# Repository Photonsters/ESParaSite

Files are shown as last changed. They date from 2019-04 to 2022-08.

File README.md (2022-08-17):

# ESParaSite temperature logger (ESP Chip-based Parameter logger with integrated website)

### Compatible with ESP8266 and ESP32

The idea for this project is to make use of the empty ESP01 slot available on the photon to make a logger to keep track of various temperatures and other data on a MSLA printer by acessing the ESP with a regular browser

Here is an example of the dashboard

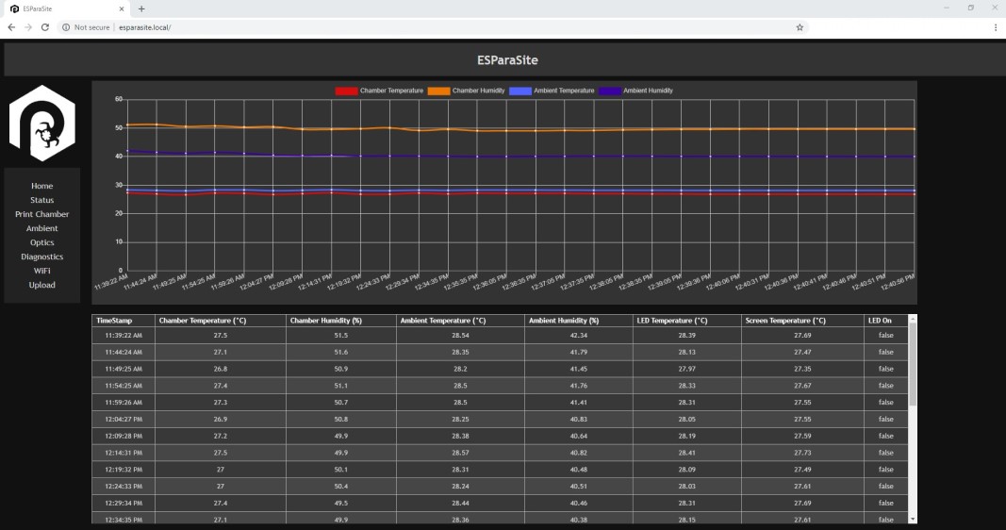
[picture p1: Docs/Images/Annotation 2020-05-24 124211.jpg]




**Check More on the [WIKI](https://github.com/Photonsters/ESParaSite_TemperatureLogger/wiki)**

Reference projects
- https://homecircuits.eu/blog/battery-powered-esp8266-iot-logger/
- http://baddotrobot.com/blog/2016/03/23/homebrew-temperature-logger/
- https://github.com/luc-github/ESP3D-WEBUI

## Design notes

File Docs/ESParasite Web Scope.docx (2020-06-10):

We are creating a data logger for 3d printers based on the ESP8266 Single board computer (type of Arduino)

The software running on the ESP8266 includes the data logger, mDNS, and a very basic webserver.

The limitations of the webserver are that it can only server files and http responses (basic web pages) so no PHP, perl or any server-side magic.

It can serve .html and .js and .css so those need to be our key tools

Not being a web guy (since the days of FrontPage, lol) I have cobbled together a website UI using

Html, css and a little javascript. Here is the “home” page.

I have run into a bunch of issues trying to do what I think is the right way to make this work.

First issue, I am loading content (home.html) into a div using jquery .load() but when I try to load other content into the div, the javascript from home.html continues to run until I call window.location.reload();

Second issue, I need to have the page refresh every 5 seconds, but after an hour or so it crashes

Third issue, I can’t get other pages to load properly no matter what I do for example (status.html) the table doesn’t execute.

The code is up on github for you to take a look.

Any help is appreciated, but mainly if you can get me going in the right direction, I am sure I can probably learn enough to make the rest work, my main struggle is just how javascript flows and interacts with the page itself.

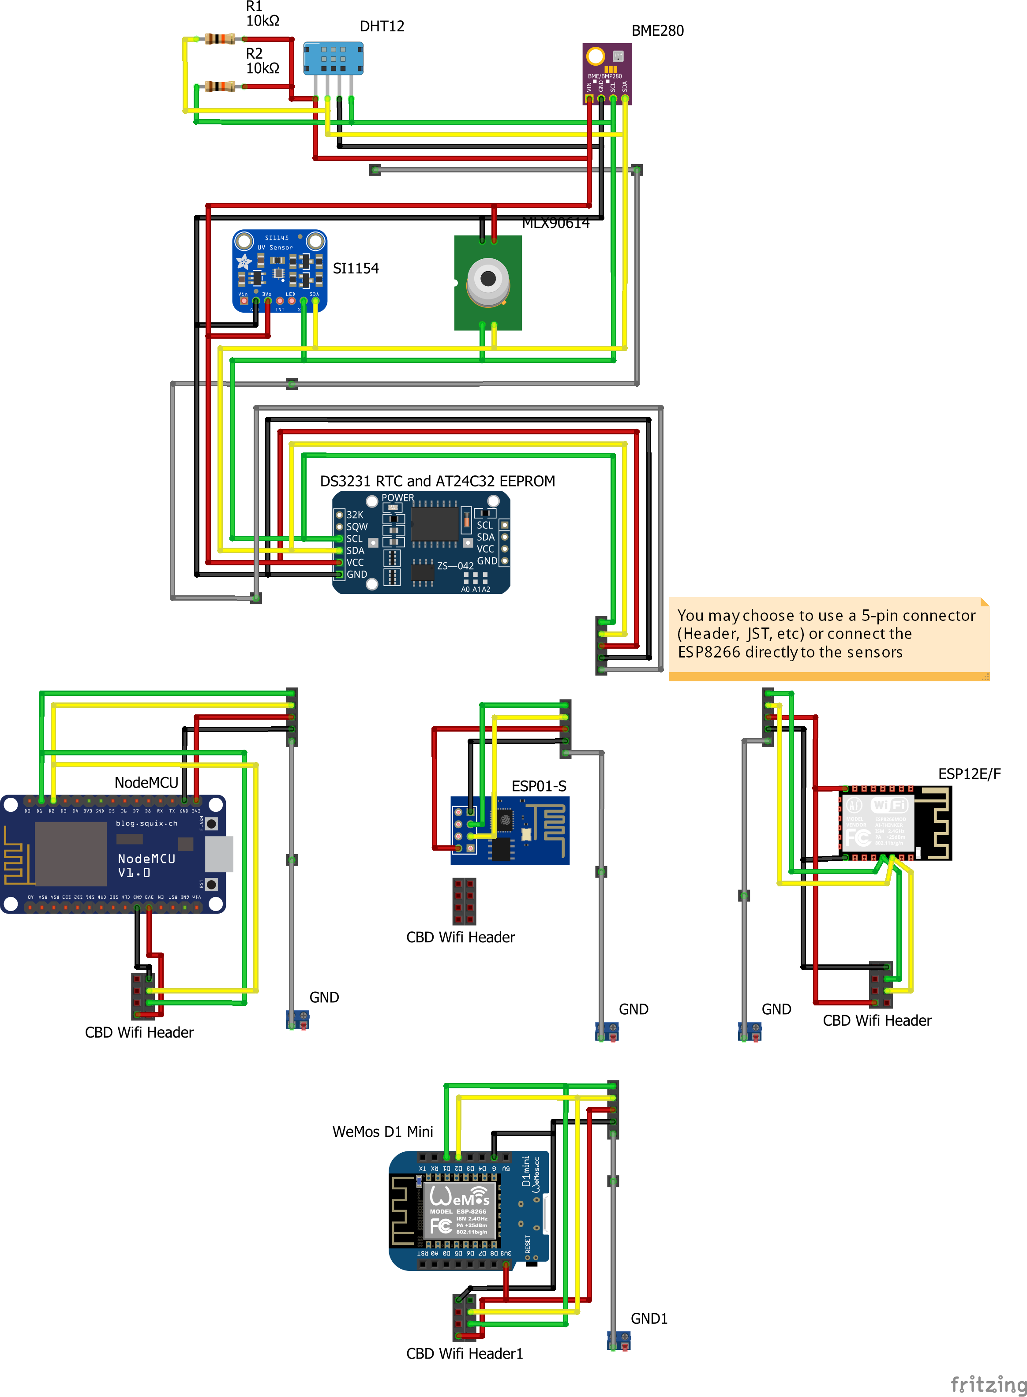
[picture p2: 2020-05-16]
Docs/Images/ESP para-site_bb.png

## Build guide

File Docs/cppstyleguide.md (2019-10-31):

ESParaSite Variable and Function naming conventions.

- NO MAGIC NUMBERS!
	- If there is a

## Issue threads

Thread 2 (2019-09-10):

Initial Config By AP Mode

CthulhuLabs, 2019-09-10:
To make it so you do not have to hard code the WiFi settings have the device initially boot up as an Access Point with a semi random SSID like "ESParaSite-1273" and no password. Use the sign in requirement of the AP force you to the config page. There have it ask for the proper SSID and Password. Once set the device resets and attempts to log into that AP. If it fails it goes back to the initial config state. If it succeeds it goes into standard operation mode.

aeakin1, 2019-09-10:
I believe this should be straightforward.  We will keep wifi config in the SPIFFS on the ESP itself.

Basic logic:
If not exists wifi config info or if wifi STA mode fails X number of times, it will boot up in AP mode and serve up a page allowing setting of SSID, Wireless PW and DHCP/Static IP.

if Wifi config is existing and connects, boot straight to STA mode.

Refer to
http://onlineshouter.com/use-esp8266-wifi-modes-station-access-point/

https://www.digikey.com/en/maker/blogs/2017/configure-your-esp8266-wifi-module-with-new-wifi-manager

aeakin1, 2019-09-16:
WiFi Manager has been successfully implemented.
If an ESParaSite boots and finds no config.json file or autoconnect credentials, It will execute the Config Portal. wifi network, password, SDA and SCL pins can be set in the portal as well as a few other handy bits of information (IP, MAC address, Board info). Once set, the portal is closed and the ESParaSite reboots, using the credentials for autoconfig.

If autoconnect fails, the unit falls back to config.json. If that fails, the Config Portal is launched.
At a later date, we will add the ability to set the fallback credentials set in the config.json file, for now they are not populated.

Closed 2019-09-16.

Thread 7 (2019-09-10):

Add (POST) RESTful capabilities for, Screen FEP and LED Counter Reset

aeakin1, 2019-09-10:

Closed 2020-05-16.

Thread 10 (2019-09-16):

Add control for Print Chamber Heater

aeakin1, 2019-09-16:
Controlling a relay via I2C seems to be difficult so this would only be available for "Advanced" boards (NodeMCU/ MiniNodeMCU/ ESP32) or potentially with a mod to an ESP-01s style board

We would use the Chamber temperature sensor and a relay to control the Heater, rather than the heater having its own controls.

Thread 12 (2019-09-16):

Lithium battery or super cap to prevent EEPROM corruption due to power off during write

aeakin1, 2019-09-16:
(High cost, High Effort, Low yield)

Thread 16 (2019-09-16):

Implement ability to set config.json fallback wifi credentials

aeakin1, 2019-09-16:
Current implementation leverages autoconnect, which uses a cached credential set during the WifiManager setup process.

Either copy autoconnect credentials or allow manual entry of the values stored in config.json for fallback.

aeakin1, 2020-06-05:
After witnessing the stability of the autoconnect routine, we are abandoning this feature.

Closed 2020-06-05.

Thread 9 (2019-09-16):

RTC EEPROM Fallback in case of corruption

aeakin1, 2019-09-16:
There is a slight chance that the Printer in which an ESParaSite is installed may be powered off while a EEPROM Write is in progress (there are 2x 50ms periods per minute in which an EEPROM update is occurring giving us a maximum risk of 100ms/60000ms. (1/100)  While this value accounts for the maximum write latency of the AT24Cxx EEPROM chip, it is likely that we would have incorrect or corrupt values.

In order to avoid this, we would need to calculate and store a checksum value on each write. All of the EEPROM values are read at boot and loaded into variables.  If this checksum fails during the read:
- we would then fall back to the previous segment of Flash (and continue to fall back until a good value is found)
- we would log an error message for each fallback
- If no good segment is found, we will format the lifetime logging segments of the EEPROM
- Potentially we will add a permanent flag that will be used to declare the EEPROM "bad" and cease logging lifetime counters until the RTC board is replaced.

Potential library
https://github.com/bakercp/CRC32

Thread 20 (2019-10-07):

Add relay control for softpower or failsafe mode

aeakin1, 2019-10-07:
The request came in as a result of a Photonster hitting a bug in the board firmware. Due to this bug, the printer was rendered powered on and somewhat operational for an extended window, while the cooling fan(s) had been shut off due to said bug. This resulted in potential damage to the LCD, LED and Mainboard components due to potential overheating.

This feature can be built to operate in two mode, selectable by the user via a config checkbox and trivial wiring change (move 1 wire from the N.O. to the N.C. screw terminal ( or visa-versa on the relay board)

# Safety shutdown mode
Safety Shutdown Mode puts a Normally Closed relay in line with the 12V power leads as they enter the chassis.

The ESParaSite can then open the relay (shutting down power to the Printer Mainboard).

## Advantages
* The ESParaSite is only responsible for opening the relay (cutting the power).
* Printing can be aborted in case of over temperature conditions being reached.
* allows us to control the printer power remotely

## Disadvantages
* less features
* If used for remote power on/off, the "off state" becomes dependent on the ESParaSite.

# Soft Power Mode
Soft Power mode puts a Normally Open relay in line with the 12V power leads as they enter the chassis.

## Advantages
* allows us to control the printer power remotely
* reduces eeprom corruption risk by allowing us to make clean writes and enter sleep mode rather than being at the mercy of when the user turns off the switch.
* allows us to cut power to the unit in case of over temperature conditions being reached.
* Could implement wake on LAN/Wifi and other handy features

## Disadvantages
* Relying on ESParaSite adds additional points of failure and complexity
* Successful prints completely depend on ESParaSite stability

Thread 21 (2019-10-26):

Add support for MS1100 VoC Sensor

aeakin1, 2019-10-26:
the MS1100 is an analog sensor for sensing VoCs.
[MS1100-ETC.pdf](https://github.com/Photonsters/ESParaSite_TemperatureLogger/files/3774395/MS1100-ETC.pdf)

X3msnake, 2019-11-26:
http://henrysbench.capnfatz.com/henrys-bench/arduino-voltage-measurements/arduino-ads1115-module-getting-started-tutorial/

X3msnake, 2019-11-27:
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

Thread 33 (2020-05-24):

GUI - Status Page

aeakin1, 2020-05-24:
Status page should show

Network Box:
Wifi status and signal strength
IP config
mDNS status

Other Status:
Eeprom last write timestamp
Printer life seconds
FEP life seconds
LCD life seconds
LED Life Seconds
Case Temperature

aeakin1, 2020-06-05:
Complete

Closed 2020-06-05.

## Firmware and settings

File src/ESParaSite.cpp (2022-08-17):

// ESParaSite.cpp

/* ESParaSite-ESP32 Data Logger
        Authors: Andy (SolidSt8Dad) Eakin

        Please see /ATTRIB for full credits and OSS License Info
        Please see /LIBRARIES for necessary libraries
        Please see /VERSION for Hstory

        All Derived Content is subject to the most restrictive licence of it's
        source.

        All Original content is free and unencumbered software released into the
        public domain.

        The Author(s) are extremely grateful for the amazing open source
        communities that work to support all of the sensors, microcontrollers,
        web standards, etc.
*/

#include <Arduino.h>
#include <FS.h>
#include <I2C_eeprom.h>

#include "API.h"
#include "ConfigPortal.h"
#include "Core.h"
#include "DebugUtils.h"
#include "ESParaSite.h"
#include "Eeprom.h"
#include "FileCore.h"
#include "Http.h"
#include "Sensors.h"
#include "Util.h"


#ifdef ESP32

#include <ESPmDNS.h>
#include <WiFi.h>

#include "ESP32.h"

#else

#include <ESP8266WiFi.h>
#include <ESP8266mDNS.h>

#include "ESP8266.h"

#endif

#ifdef ESP32

#include <SPIFFS.h>
FS *filesystem = &SPIFFS;
#define FileFS SPIFFS

#else

#include <LittleFS.h>
FS *filesystem = &LittleFS;
#define FileFS LittleFS

#endif

// The structs used to carry data globally
ESParaSite::ambientData ambient;
ESParaSite::configData config;
ESParaSite::enclosureData enclosure;
ESParaSite::opticsData optics;
ESParaSite::chamberData chamber;
ESParaSite::eepromData eeprom;
ESParaSite::statusData status;
ESParaSite::machineData machine;

#ifdef ESP32
// Trigger for inititating config mode is Pin D0 and also flash button on
// NodeMCU. Flash button is convenient to use but if it is pressed it will
// hang the serial port device driver until the computer is rebooted on
// Windows machines.

// Pin D0 mapped to pin GPIO0/BOOT/ADC11/TOUCH1 of ESP32
const int TRIGGER_PIN = PIN_D0;

// Alternative trigger pin. Needs to be connected to a button to use this pin.
// It must be a momentary connection not connected permanently to ground. Either
// trigger pin will work.

// Pin D25 mapped to pin GPIO25/ADC18/DAC1 of ESP32
const int TRIGGER_PIN2 = PIN_D25;

#else
// Trigger for inititating config mode is Pin D3 and also flash button on
// NodeMCU. Flash button is convenient to use but if it is pressed it will
// hang the serial port device driver until the computer is rebooted on
// Windows machines.

const byte TRIGGER_PIN = PIN_D3;

// Alternative trigger pin. Needs to be connected to a button to use this pin.
// It must be a momentary connection not connected permanently to ground. Either
// trigger pin will work.

// Pin D0 mapped to pin GPIO16/USER/WAKE of ESP8266.
const byte TRIGGER_PIN2 = PIN_D0;
#endif

// Variables used to service the loop
uint16_t curLoopMillis = 0;
uint16_t prevSensorMillis = 0;
uint16_t prevDhtMillis = 0;
uint16_t prevEepromMillis = 0;
uint16_t prevHistoryMillis = 0;
uint16_t prevLedMillis = 0;

// will store LED state
// int ledState = LED_ON;

// interval at which to blink (milliseconds)
// const long interval = 1000;

// **********************************************************
// SETUP
// **********************************************************
void setup() {
  // Set up pins
  pinMode(LED_BUILTIN, OUTPUT);

  // Initialize trigger pins
  pinMode(TRIGGER_PIN, INPUT_PULLUP);
  pinMode(TRIGGER_PIN2, INPUT_PULLUP);

  // Begin Serial Output
  Serial.begin(115200);
  Serial.println();

  Serial.println();
  Serial.println("ESParaSite Data Logging Server");
  Serial.println("https://github.com/Photonsters/ESParaSite-ESP32");
  Serial.print("Compiled: ");
  Serial.print(__DATE__);
  Serial.print("\t");
  Serial.println(__TIME__);
  Serial.println();

  // Turn onboard LED on
  digitalWrite(LED_BUILTIN, LED_ON);

  // For Development Only.  FORMAT_FileFS can be uncommented in DebugUtils.h.
#ifdef FORMAT_FileFS
  Serial.println("Formatting SPIFFS/LittleFS...");
  FileFS.format();
#endif

  // Attempt to mount the FileFS Filesystem. If failure assumethat this is
  // first boot and format FileFS Filesystem.

  Serial.println("Mounting FS...");

  if (!FileFS.begin()) {
    Serial.println("Failed to mount FileFS file system. This is likely the "
                   "first boot of this device. Formatting FileFS");
    FileFS.format();
  } else {
    Serial.println("File system mounted");
    Serial.println();
  }

  //#ifdef DEBUG_L2
  // Dump the contents of SPIFFS/LittleFS filesystem to serial console.
  ESParaSite::APIHandler::getFSInfo(1);
  ESParaSite::APIHandler::getFSList(1);
  //#endif

  // Attempt to load the config.json file. If it does not exist, launch Wifi
  // Config Portal. If it exists, parse it.
  if (!ESParaSite::FileCore::loadConfig()) {
    Serial.println("There was a problem with the config.json file. Booting "
                   "in Config Portal mode.");
    ESParaSite::ConfigPortal::doConfigPortal();
  } else {
    Serial.println("config.json loaded.");
  }

  // Check if Wifi is configured. Failure forces boot into captive portal.
  Serial.println("Configuring Wifi...");
  Serial.println();

  if (strcmp(config.cfgWifiSsidChar, "") == 0) {
    Serial.println(
        F("WiFi credentials unset, Booting in AP Config Portal mode."));
    ESParaSite::ConfigPortal::doConfigPortal();
  } else {
    // Connect to Access Point
    Serial.println("Connecting to Wifi...");
    WiFi.begin(config.cfgWifiSsidChar, config.cfgWifiPasswordChar);

#ifndef DEBUG_L1
    // Wait for WiFi connection.
    WiFi.waitForConnectResult();
#endif

#ifdef DEBUG_L1
    // Wait for WiFi connection. Time how long it takes to connect.
    unsigned long startedAt = millis();
    Serial.print("After waiting ");
    int8_t connRes = WiFi.waitForConnectResult();
    float waited = (millis() - startedAt);
    Serial.print(waited / 1000);
    Serial.print(" secs in setup() connection result is ");
    Serial.println(connRes);
#endif
  }

  // Print Wifi Status and IP. If Wifi connection times out, launch config
  // portal.
  if (WiFi.status() != WL_CONNECTED) {
    Serial.println("Failed to connect, Booting in AP Config Portal"
                   "mode.");
    ESParaSite::ConfigPortal::doConfigPortal();
  } else {
    Serial.print("Wifi Connected to: ");
    Serial.println(WiFi.SSID());
    Serial.print("IP Address: ");
    Serial.println(WiFi.localIP());
    Serial.println();
  }

  // Start mDNS if enabled
  Serial.println("Configuring mDNS...");

  if (config.cfgMdnsEnabled == 1) {
    const char *mdnsN = config.cfgMdnsName;
    if (!MDNS.begin(mdnsN)) {
      // Start the mDNS responder <cfgMdnsName>.local
      Serial.println("Error setting up MDNS responder!");
      ESParaSite::ConfigPortal::doConfigPortal();
    } else {
      Serial.println("mDNS responder started");
      Serial.println("mDNS enabled on URL:");
      Serial.print("http://");
      Serial.print(config.cfgMdnsName);
      Serial.println(".local");
      Serial.println();
    }
  }

  // Initialize I2C bus, sensors and RTC module.
  Serial.println("Initializing i2c bus, sensors and rtc...");
  Serial.println();
  if (!(config.cfgPinSda) || !(config.cfgPinScl)) {
    ESParaSite::Sensors::initI2cSensors(PIN_SDA, PIN_SCL);
  } else {
    ESParaSite::Sensors::initI2cSensors(config.cfgPinSda, config.cfgPinScl);
  }

#ifdef DEBUG_L2
  // Dump all sensor data to serial console
  ESParaSite::Sensors::dumpSensor(false);
#endif

  // Initialize i2c eeprom
  Serial.println("Initializing i2c eeprom...");
  Serial.println();

  if (!ESParaSite::Eeprom::initI2cEeprom()) {
    Serial.println("No EEPROM Device Found, Please Check I2C Pins. Booting "
                   "in Config Portal mode.");
    ESParaSite::ConfigPortal::doConfigPortal();
  } else {
    ESParaSite::Eeprom::initEeprom();
  }

  // For Development Only.  FORMAT_EEPROM can be uncommented in DebugUtils.h.
#ifdef FORMAT_EEPROM
  ESParaSite::RtcEeprom::doEepromFormat(1);
#endif

  // Find the most recent EEPROM segment and populate our eeprom_data struct.
  uint16_t mruPageAddr = ESParaSite::Eeprom::doEepromFirstRead();

#ifdef DEBUG_L1
  Serial.print("The most recent write address:\t");
  Serial.print(mruPageAddr);
  Serial.print(" (0x");
  Serial.print(mruPageAddr, HEX);
  Serial.println(")");
  Serial.println();
#endif

  ESParaSite::Eeprom::doEepromRead(mruPageAddr);

  Serial.println("Startup Complete!");
  Serial.println();

#ifdef RESET_LIFE_COUNTERS
  eeprom.eepromVatLifeSec = 0;
  eeprom.eepromLedLifeSec = 0;
  eeprom.eepromScreenLifeSec = 0;
#endif

  ESParaSite::HttpCore::configHttpServerRouting();
  ESParaSite::HttpCore::startHttpServer();

#ifdef DEBUG_L1
  Serial.println("Waiting 3 Seconds...");
  delay(3000);
#endif

  // Turn led off as we are finished booting.
  digitalWrite(LED_BUILTIN, LED_OFF);
}

// **********************************************************
// LOOP
// **********************************************************
void loop() {
  // Check to see if Config Mode Triggered
  if ((digitalRead(TRIGGER_PIN) == LOW) || (digitalRead(TRIGGER_PIN2) == LOW)) {
    Serial.println("Configuration portal requested.");
    ESParaSite::ConfigPortal::doConfigPortal();
  }

  // Refresh the Current Loop Millisecond value
  curLoopMillis = millis();

#ifdef DEBUG_L4
  Serial.print("curLoopMillis:\t");
  Serial.println(curLoopMillis);
  Serial.print("prevSensorMillis:\t");
  Serial.println(prevSensorMillis);
  Serial.print("prevDhtMillis:\t");
  Serial.println(prevDhtMillis);
  Serial.print("prevEepromMillis:\t");
  Serial.println(prevEepromMillis);
  Serial.println();
#endif

#ifdef DEBUG_L4
  Serial.println("Checking to see if we need to read Sensors");
  Serial.println();
#endif

  // Read sensors if it has been the right interval
  prevSensorMillis =
      ESParaSite::Core::doReadSensors(curLoopMillis, prevSensorMillis);

#ifdef DEBUG_L4
  Serial.println("Checking to see if we need to read DHT12 Sensor");
  Serial.println();
#endif

  // Read the DHT12 sensor if it has been the right interval
  prevDhtMillis = ESParaSite::Core::doReadDht(curLoopMillis, prevDhtMillis);

#ifdef DEBUG_L4
  Serial.println("Checking to see if we need to Write to EEPROM");
  Serial.println();
#endif

  // Update EEPROM and memory values
  prevEepromMillis =
      ESParaSite::Core::doHandleEeprom(curLoopMillis, prevEepromMillis);

#ifdef DEBUG_L4
  Serial.println("Create History Digest");
  Serial.println();
#endif

  // Keep track of historical data and update Web UI data
  prevHistoryMillis =
      ESParaSite::Core::doHandleHistory(curLoopMillis, prevHistoryMillis);

#ifdef DEBUG_L2
  Serial.println("End of loop waiting 500msec");
  delay(500);
#endif
}

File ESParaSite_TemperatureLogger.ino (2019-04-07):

/* ESParasite Data Logger v0.2
	Authors: Andy  (SolidSt8Dad)Eakin

	  Please see /ATTRIB for full credits and OSS License Info
  	Please see /LIBRARIES for necessary libraries
  	Please see /VERSION for Hstory

	All Derived Content is subject to the most restrictive licence of it's source.

	All Original content is free and unencumbered software released into the public domain.
*/
#include <ESP8266WiFi.h>
#include <WiFiClient.h>
#include <ESP8266WebServer.h>
#include <ArduinoJson.h>
#include <Wire.h>
#include <Adafruit_Sensor.h>
#include <Adafruit_SI1145.h>
#include <Adafruit_MLX90614.h>
#include <dht.h>
#include <EepromAT24C32.h>
#include <RtcDateTime.h>
#include <RtcDS3231.h>
#include <RtcTemperature.h>
#include <RtcUtility.h>
#include <BlueDot_BME280.h>

//+++ User Settings +++
//const char* wifi_ssid     = "yourwifinetwork";
//const char* wifi_password = "yourwifipassword";


//+++ Advanced Settings +++
// For precise altitude measurements please put in the current pressure corrected for the sea level
// Otherwise leave the standard pressure as default (1013.25 hPa);
// Also put in the current average temperature outside (yes, really outside!)
// For slightly less precise altitude measurements, just leave the standard temperature as default (15°C and 59°F);
#define SEALEVELPRESSURE_HPA (1013.25)
#define CURRENTAVGTEMP_C (15)
#define CURRENTAVGTEMP_F (59)

#define HTTP_REST_PORT 80

//Set the I2C address of your breakout board
//int bme_i2c_address = 0x77;
int bme_i2c_address = 0x76;


//Initialize Libraries
ESP8266WebServer http_rest_server(HTTP_REST_PORT);
dht12 DHT(0x5c);
Adafruit_MLX90614 mlx = Adafruit_MLX90614();
Adafruit_SI1145 uv = Adafruit_SI1145();
BlueDot_BME280 bme;
RtcDS3231<TwoWire> Rtc(Wire);
EepromAt24c32<TwoWire> RtcEeprom(Wire);

char daysOfTheWeek[7][12] = {"Sunday", "Monday", "Tuesday", "Wednesday", "Thursday", "Friday", "Saturday"};
unsigned long delayTime;
int bmeDetected = 0;

struct printchamber {
  float dht_temp_c;
  float dht_humidity;
  float dht_dewpoint;
} chamber_resource;

struct optics {
  float si_uvindex;
  float si_visible;
  float si_infrared;
  float mlx_amb_temp_c;
  float mlx_obj_temp_c;
} optics_resource;

struct ambient {
  float bme_temp_c;
  float bme_humidity;
  float bme_barometer;
  float bme_altitude;
} ambient_resource;

struct enclosure {
  float case_temp;
  float total_sec;
  float screen_sec;
  float led_sec;
} enclosure_resource;

RtcDateTime now;
char timestamp[14];

void loop(void) {
  http_rest_server.handleClient();
}

int init_wifi() {
  // Connect to WiFi network
  WiFi.begin(wifi_ssid, wifi_password);
  Serial.print("\n\r \n\rConnecting to Wifi");
  // Wait for connection
  while (WiFi.status() != WL_CONNECTED) {
    delay(500);
    Serial.print(".");
  }
  return WiFi.status(); // return the WiFi connection status
}

void init_chamber_resource() {
  chamber_resource.dht_temp_c = 0;
  chamber_resource.dht_humidity = 0;
  chamber_resource.dht_dewpoint = 0;
}

void init_optics_resource() {
  optics_resource.si_uvindex = 0;
  optics_resource.si_visible = 0;
  optics_resource.si_infrared = 0;
  optics_resource.mlx_amb_temp_c = 0;
  optics_resource.mlx_obj_temp_c = 0;
}

void init_ambient_resource() {
  ambient_resource.bme_temp_c = 0;
  ambient_resource.bme_humidity = 0;
  ambient_resource.bme_barometer = 0;
  ambient_resource.bme_altitude = 0;
}

void init_enclosure_resource() {
  enclosure_resource.case_temp = 0;
  enclosure_resource.total_sec = 0;
  enclosure_resource.screen_sec = 0;
  enclosure_resource.led_sec = 0;
}

void config_rest_server_routing() {
  http_rest_server.on("/", HTTP_GET, []() {
    http_rest_server.send(200, "text/html",
                          "Welcome to the ESParasite REST Web Server");
  });
  http_rest_server.on("/printchamber", HTTP_GET, get_chamber);
  http_rest_server.on("/optics", HTTP_GET, get_optics);
  http_rest_server.on("/ambient", HTTP_GET, get_ambient);
  http_rest_server.on("/enclosure", HTTP_GET, get_enclosure);
  // http_rest_server.on("/enclosure", HTTP_POST, post_enclosure); //Not yet implemented
  // http_rest_server.on("/enclosure", HTTP_PUT, post_enclosure);  //Not yet implemented
}

void get_chamber () {

  read_dht_sensor();
  read_rtc_data();
  create_timestamp(now);

  StaticJsonDocument<256> doc;

  doc["class"] = "chamber";
  doc["timestamp"] = timestamp;
  doc["seconds_t"] = chamber_resource.dht_temp_c;
  doc["seconds_s"] = chamber_resource.dht_humidity;
  doc["seconds_l"] = chamber_resource.dht_dewpoint;

  serializeJson(doc, Serial);
  Serial.println();

  String output = "JSON = ";
  serializeJsonPretty(doc, output);
  http_rest_server.send(200, "application/json", output);

  serializeJsonPretty(doc, Serial);
  Serial.println();
}

void get_optics () {

  read_si_sensor();
  read_mlx_sensor();
  read_rtc_data();
  create_timestamp(now);

  StaticJsonDocument<256> doc;

  doc["class"] = "optics";
  doc["timestamp"] = timestamp;
  doc["uvindex"] = optics_resource.si_uvindex;
  doc["visible"] = optics_resource.si_visible;
  doc["infrared"] = optics_resource.si_infrared;
  doc["led_temp_c"] = optics_resource.mlx_amb_temp_c;
  doc["screen_temp_c"] = optics_resource.mlx_obj_temp_c;

  serializeJson(doc, Serial);
  Serial.println();

  String output = "JSON = ";
  serializeJsonPretty(doc, output);
  http_rest_server.send(200, "application/json", output);

  serializeJsonPretty(doc, Serial);
  Serial.println();
}

void get_ambient() {

  read_bme_sensor();
  read_rtc_data();
  create_timestamp(now);

  StaticJsonDocument<256> doc;

  doc["class"] = "ambient";
  doc["timestamp"] = timestamp;
  doc["amb_temp_c"] = ambient_resource.bme_temp_c;
  doc["amb_humidity"] = ambient_resource.bme_humidity;
  doc["amb_pressure"] = ambient_resource.bme_barometer;
  doc["altitude"] = ambient_resource.bme_altitude;

  serializeJson(doc, Serial);
  Serial.println();

  String output = "JSON = ";
  serializeJsonPretty(doc, output);
  http_rest_server.send(200, "application/json", output);

  serializeJsonPretty(doc, Serial);
  Serial.println();
}

void get_enclosure() {

  read_rtc_data();
  //  read_at24_data();   //Placeholder - Not yet Implemented
  create_timestamp(now);

  StaticJsonDocument<256> doc;

  doc["class"] = "enclosure";
  doc["timestamp"] = timestamp;
  doc["case_temp"] = enclosure_resource.case_temp;
  doc["seconds_t"] = enclosure_resource.total_sec;  //Placeholder - Not yet Implemented
  doc["seconds_s"] = enclosure_resource.screen_sec; //Placeholder - Not yet Implemented
  doc["seconds_l"] = enclosure_resource.led_sec;    //Placeholder - Not yet Implemented

  serializeJson(doc, Serial);
  Serial.println();

  String output = "JSON = ";
  serializeJsonPretty(doc, output);
  http_rest_server.send(200, "application/json", output);

  serializeJsonPretty(doc, Serial);
  Serial.println();
}
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

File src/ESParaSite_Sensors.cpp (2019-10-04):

// ESParaSite_Sensors.cpp

/* ESParasite Data Logger v0.5
	Authors: Andy  (SolidSt8Dad)Eakin

	Please see /ATTRIB for full credits and OSS License Info
  	Please see /LIBRARIES for necessary libraries
  	Please see /VERSION for Hstory

	All Derived Content is subject to the most restrictive licence of it's source.

	All Original content is free and unencumbered software released into the public domain.
*/

#include <Arduino.h>
#include <Wire.h>
#include <Time.h>
#include <BlueDot_BME280.h>
#include <dht12.h>
#include <Adafruit_Sensor.h>
#include <Adafruit_SI1145.h>
#include <Adafruit_MLX90614.h>
#include <RtcDS3231.h>
#include <EepromAt24C32.h>

#include "ESParaSite_Core.h"
#include "ESParaSite_Rest.h"
#include "ESParaSite_Eeprom.h"
#include "ESParaSite_Sensors.h"

#define countof(a) (sizeof(a) / sizeof(a[0]))

//+++ Advanced Settings +++
// For precise altitude measurements please put in the current pressure corrected for the sea level
// Otherwise leave the standard pressure as default (1013.25 hPa)

// Also put in the current average temperature outside (yes, really outside!)
// For slightly less precise altitude measurements, just leave the standard temperature as default (15°C and 59°F);
#define SEALEVELPRESSURE_HPA (1013.25)
#define CURRENTAVGTEMP_C (15)
#define CURRENTAVGTEMP_F (59)

// These values control the I2C address of each sensor. Some chips may use different addresses and it is recommend
// to utilize the I2C scanner sketch at:
// https://gist.github.com/AustinSaintAubin/dc8abb2d168f5f7c27d65bb4829ca870
// to scan for your sensors if you are having any issues with communication.

// DHT12 Sensor Address. Default (0x5C)
#define DHT_ADDR (0x5C)
// SI1145 Sensor Address. Default (0x60)
#define SI_ADDR (0x60)
// MLX90614 Sensor Address. Default (0x5A)
#define MLX_ADDR (0x5A)
// BME280 Sensor Address. Default (0x76) or (0x77)
#define BME_ADDR_A (0x76)
#define BME_ADDR_B (0x77)
// DS3231 Real Time Clock Address. Default (0x68)
#define RTC_ADDR (0x68)
// AT24C32 EEPROM Address. Default (0x50 to 0x57)
#define RTC_EEPROM_BASE_ADDR (0x50)
#define RTC_EEPROM_MAX_ADDR (0x57)

//*** DO NOT MODIFY ANYTHING BELOW THIS LINE ***

int bme_i2c_address;
int eeprom_i2c_address;
int bmeDetected = 0;
int dhtDetected = 0;
int mlxDetected = 0;
int rtcDetected = 0;
int siDetected = 0;

extern config_data config_resource;

Adafruit_MLX90614 mlx = Adafruit_MLX90614();
Adafruit_SI1145 uv = Adafruit_SI1145();
RtcDS3231<TwoWire> rtc(Wire);
BlueDot_BME280 bme;
DHT12 dht;

// Since we use libraries by different authors, not all libraries talk to sensors in the same way.
// init_i2c_sensors and ping_sensor give us a cleaner, abstracted format to check fo rthe sensors before calling the
// init_xyz_sensor() methods which are unique to the sensor and library chosen.
// This will allow us to extend sensor support over time in a more elegant fashion.

void init_i2c_sensors()
{
  // initialize I2C bus
  Serial.print("Init I2C bus...");
  Wire.begin(config_resource.cfg_pin_sda, config_resource.cfg_pin_scl);
  Serial.println("\t\t\t\t\t\t\tOK!");
  Serial.println();

  // initialize Print Chamber sensor
  Serial.print("Init Print Chamber Sensor...");
  int error = ping_sensor(DHT_ADDR);
  if (error == 0)
  {
    init_dht_sensor();
  }
  Serial.println();

  // initialize UV Light sensor
  Serial.print("Init UV Light sensor...");
  error = ping_sensor(SI_ADDR);
  if (error == 0)
  {
    init_si_sensor();
  }
  Serial.println();

  // initialize Non-Contact temperature sensor
  Serial.print("Init Non-Contact temperature sensor...");
  error = ping_sensor(MLX_ADDR);
  if (error == 0)
  {
    init_mlx_sensor();
  }
  Serial.println();

  // initialize BME280 temperature sensor
  Serial.print("Init BME280 sensor...");
  error = ping_sensor(BME_ADDR_A);
  if (error == 0)
  {
    bme_i2c_address = (BME_ADDR_A);
    init_bme_sensor();
  }
  else
  {
    error = ping_sensor(BME_ADDR_B);
    if (error == 0)
    {
      bme_i2c_address = (BME_ADDR_B);
      init_bme_sensor();
    }
  }
  Serial.println();

  // initialize DS3231 RTC
  Serial.print("Init DS3231 RTC...");
  error = ping_sensor(RTC_ADDR);
  if (error == 0)
  {
    Serial.println("OK!");
    init_rtc_clock();
  }

  // initialize AR24C32 EEPROM
  Serial.println("Init AT24C32 EEPROM...");

  for (eeprom_i2c_address = RTC_EEPROM_BASE_ADDR; eeprom_i2c_address <= RTC_EEPROM_MAX_ADDR; eeprom_i2c_address++)
  {
    error = ping_sensor(eeprom_i2c_address);
    if (error == 0)
    {
      Serial.println("OK!");
      Serial.println();
      init_rtc_eeprom();
      return;
    }
    Serial.println();
  }
  Serial.println("NO EEPROM FOUND!");
  Serial.println();
}

int ping_sensor(int address)
{
  byte error;
  Wire.beginTransmission(address);
  error = Wire.endTransmission();

  if (error == 0)
  {
    Serial.print("I2C device found at address 0x");
    if (address < 16)
      Serial.print("0");
    Serial.print(address, HEX);
    Serial.print("\t\t");
  }
  else if (error == 2)
  {
    Serial.print("No device (Ping recieved NACK) at address 0x");
    if (address < 16)
      Serial.print("0");
    Serial.print(address, HEX);
    Serial.print("\t\t");
  }
  else if (error == 4)
  {
    Serial.print("Unknown error at address 0x");
    if (address < 16)
      Serial.print("0");
    Serial.print(address, HEX);
    Serial.print("\t\t");
  }
  return error;
}

// This gives us a nicely formatted dump of all sensor data to Serial console.
void dump_sensors()
{
  Serial.println();
  Serial.println("Current Sensor Readings");
  Serial.println("============================================================");
  Serial.println();

  Serial.println("DS3231 Real-Time Clock Timestamp and Temperature:");
  read_rtc_data();
  Serial.println();

  Serial.println("dht12 Print Chamber Environmental Data:");
  read_dht_sensor();
  Serial.println();

  Serial.println("SI1145 UV and Light Sensor Data:");
  read_si_sensor();
  Serial.println();

  Serial.println("MLX90614 LED Temp Sensor Data:");
  read_mlx_sensor();
  Serial.println();

  Serial.println("BME280 Ambient Temp Sensor Data:");
  read_bme_sensor();
  Serial.println();

  // Comment this line out for Production
}

void init_dht_sensor()
{
  int status = dht.read();
  switch (status)
  {
  case DHT12_OK:
    Serial.print("OK!\t");
    dhtDetected = 1;
    break;
  case DHT12_ERROR_CHECKSUM:
    Serial.print("Checksum error,\t");
    break;
  case DHT12_ERROR_CONNECT:
    Serial.print("Connect error,\t");
    break;
  case DHT12_MISSING_BYTES:
    Serial.print("Missing bytes,\t");
    break;
  default:
    Serial.print("Unknown error,\t");
    break;
  }
}

void init_si_sensor()
{
  if (!uv.begin())
  {
    Serial.print("SI1145 Initialization Failure!");
  }
  else
  {
    siDetected = 1;
    Serial.print("OK!");
  }
}

void init_mlx_sensor()
{
  if (!mlx.begin())
  {
    Serial.print("MLX90614 Initialization Failure");
  }
  else
  {
    mlxDetected = 1;
    Serial.print("OK!");
  }
}
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

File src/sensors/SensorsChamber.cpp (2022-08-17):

// SensorsChamber.cpp

/* ESParaSite-ESP32 Data Logger
        Authors: Andy (SolidSt8Dad) Eakin

        Please see /ATTRIB for full credits and OSS License Info
        Please see /LIBRARIES for necessary libraries
        Please see /VERSION for Hstory

        All Derived Content is subject to the most restrictive licence of it's
        source.

        All Original content is free and unencumbered software released into the
        public domain.

        The Author(s) are extremely grateful for the amazing open source
        communities that work to support all of the sensors, microcontrollers,
        web standards, etc.
*/

#include <Arduino.h>
#include <DHT12.h>
#include <Wire.h>

#include "DebugUtils.h"
#include "ESParaSite.h"
#include "Sensors.h"
#include "Util.h"

//+++ Advanced Settings +++

// These values control the I2C address of each sensor. Some chips may use
// different addresses and it is recommend to utilize the I2C scanner sketch at:
// https://gist.github.com/AustinSaintAubin/dc8abb2d168f5f7c27d65bb4829ca870
// to scan for your sensors if you are having any issues with communication.

// DHT12 Sensor Address. Default (0x5C)
#define DHT_ADDR (0x5C)

//*** DO NOT MODIFY ANYTHING BELOW THIS LINE ***

extern DHT12 dev_dht;

extern ESParaSite::chamberData chamber;
extern ESParaSite::machineData machine;

void ESParaSite::Sensors::initDhtSensor() {
  dev_dht.begin();
  int8_t status = dev_dht.readStatus();
  switch (status) {
  case DHT12::OK:
    Serial.println(F("OK!"));
    machine.dhtDetected = 1;
    break;
  case DHT12::ERROR_CHECKSUM:
    Serial.println(F("Checksum error"));
    break;
  case DHT12::ERROR_TIMEOUT:
    Serial.println(F("Timeout error"));
    break;
  case DHT12::ERROR_TIMEOUT_LOW:
    Serial.println(
        F("Timeout error on low signal, try put high pullup resistance"));
    break;
  case DHT12::ERROR_TIMEOUT_HIGH:
    Serial.println(
        F("Timeout error on low signal, try put low pullup resistance"));
    break;
  case DHT12::ERROR_CONNECT:
    Serial.println(F("Connect error"));
    break;
  case DHT12::ERROR_ACK_L:
    Serial.println(F("AckL error"));
    break;
  case DHT12::ERROR_ACK_H:
    Serial.println(F("AckH error"));
    break;
  case DHT12::ERROR_UNKNOWN:
    Serial.println(F("Unknown error DETECTED"));
    break;
  case DHT12::NONE:
    Serial.println(F("No result"));
    break;
  default:
    Serial.println(F("Unknown error"));
    break;
  }
}

void ESParaSite::Sensors::readDhtSensor(bool inLoopRead, bool print) {
  // First dht measurement is stale, so if inLoopRead is 'false' (when read is
  // out-of-loop or, in other words, not called by a timer in the loop() ),
  // we read, wait 2 seconds, then read again. Normal in sequence reads do not
  // need this, so we send a 'true' to skip the additional delay.
  if (machine.dhtDetected == 1) {

    bool dht12Read = true;
    if (!inLoopRead) {
      // Read temperature as Celsius (the default)
      float dhtTempC = dev_dht.readTemperature();
      // Check if any reads failed and exit early (to try again).

      if (isnan(dhtTempC)) {
        Serial.println("Failed to read from DHT12 sensor!");

        dht12Read = false;
      }
      if (dht12Read) {
        delay(2000);
      }
    }

    if (dht12Read) {
      // Read temperature as Celsius (the default)
      float dhtTempC = dev_dht.readTemperature();
      chamber.chamberTempC = ESParaSite::Util::floatToTwo(dhtTempC);

      if (isnan(dhtTempC)) {
        Serial.println("Failed to read from DHT12 sensor!");
        chamber.chamberTempC = 0;
      }
    }

#ifdef DEBUG_L2
    Serial.println(F("==========Print Chamber Sensor=========="));
    print = true;
#endif

    if (print == true) {
      Serial.print(F("Temperature:\t\t\t"));
      Serial.print((chamber.chamberTempC));
      Serial.print("°C / ");
      Serial.print(Util::convertCtoF((chamber.chamberTempC)));
      Serial.println("°F");
    }
  }
}

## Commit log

2019-03-20 added reference esp01 on a photon board
2019-03-30 Create Component Arduino Libraries
    Created file to collect Arduino library links for components
2019-04-01 Update Component Arduino Libraries
    Updated to add DHT12, MLX90614 and DS3231/AT24C32 links
2019-04-01 Add files via upload
    Beta version of Fritzing Schematic
2019-04-02 Update Component Arduino Libraries
    Updated Used/Unused
2019-04-08 Moved Component Arduino Libraries to Wiki
2019-09-10 Updated to MVP
    Added connections for NodeMCU and ESP-12F.
    Updated connections for clarity
    added Drain wire to chassis
    [ESP para-site.fzz]
2019-09-10 touched up a misrouted wire
    [ESP para-site.fzz]
2019-09-17 First commit for v0.5
    - Moved WiFi functions to their own file ESParaSite_Wifi.cpp
    - Added ESParaSite_FileConfig.cpp for config file functions
    - Implemented SPIFFS for /config.json (Issue #3)
    - Added initial config via Web Portal (Issue #2)
    [ESParaSite_Sensors.cpp]
2019-10-04 WIP 1 Commit
    - Fixed a bug in ESParaSite_Eeprom.cpp where we issued a return prior to setting a variable in 2 places.
    - Added for() loop to scan all 8 I2C addresses of an AT24Cx EEPROM
    - Added Magic number warning comments in ESParaSite_Eeprom.cpp for the functions that assume an eeprom layout (we will go back and fix that IF a different chip becomes common)
    - cppcheck/cpplint work to clean up code
    - 120 char max lines (I had 80 columns in 1982, lets move on, folks /me ducks)
    - replaced less secure string (strcat, sprintf, etc) functions with 'snprintf' (Security/Modern Semantics)
    - reduced scope of a number of variables.
    - removed a couple of extraneous variables
    - changed to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
    [ESP para-site.fzz]
2019-10-31 Documentation Updates
    [ESP para-site - ESP12F Advanced.fzz, ESP para-site.fzz]
2020-05-12 Completion of v0.6
    v0.6 - Sixth Release -
    - removed a couple of extrane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
    [ESParaSite.cpp]
2020-05-13 Release of v0.7
    v0.7 - Seventh Release -
    - Implemented LittleFS for /config.json to replace deprecated SPIFFS. This will require a new config file to be written. Thus a new run of the Config Portal.
    - This is destructive to any exsisting SPIFFS data, but since we only use it for the config.json currently, it will simply force you back into the Config Portal
    - Cleaned up some code in ESParaSite_Sensors.cpp
    - reduced serial verbosity, we no longer constantly dump sensor data to serial, except when in DEBUG_L2. We normally only do a sensor dump upon EEPROM Write.
    - Cleaned up and moved some RTC tasks to other functions to limit redundant code.
    - Continued moving serial.print() to seri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
    [ESParaSite.cpp]
2020-05-14 First commit for v0.8
    - Separated HTTP routines into Core and Handler files. This will make
    code easier to scale.
    - Implemented ESP32-Targz as a hardcoded library.
    - This will allow us to upload and unarchive .gz, .tar.gz and .tar
    files
    - gunzip is extremely memory intensive and may not be supported
    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
2020-05-16 Final Beta Commit for v0.8
    v0.8 - Heterophyiasis - 2020-05-15
    long term
    - the main point of adding this is to be able to upload a website
    "package" so the web GUI can be uploaded and upgraded
    separately from the core code.
    - Implemented HTTP Uploads to SPIFFS
    - Implemented HTTP POST methods to allow reset of lifetime counters for LCD
    Screen, LED Array and Vat FEP
    - Started to rename variable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
    [ESParaSite.cpp]
2020-05-16 Drawings updated
    [ESP para-site.fzz]
2020-06-08 continuing work on v.10
    - Split SensorsCore.cpp into multiple files for easier maintenance and
    future growth for alternate sensors.
    - Renamed ESParaSite_ files to remove prefix.
    - Added routine to allow remotely setting of the Real Time Clock to UTC
    currently performed alongside GUI upload.
    - UPLOADER - added time setting function that sets the RTC to UTC
    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
2020-06-15 Code Cleanup and bugfixes
    - Fixed BugIssue #39 api feeds for fileList and readHistory now send 2kB
    chunks of data across multiple HTTP chunks.
    - Changed digest of data to add hourly digests for 12 hours. We now
    provide 40 datapoiints - live data every 5 seconds for 30 seconds,
    30 second data averages for 5 minutes, 5 minute data average for
    1 hour and 1 hour averages for 12 hours.
    - Renamed RtcEepromCore.h and .cpp to EepromCore.h and .cpp.
    - Numerous changes to header and source file naming and src folder layout
    - This should make the code groupings a bit simpler for humans to
    follow and keep the root sprawl to a minimum
    - GUI - added regex parsing prior to parsing json d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
    [ConfigPortal.cpp, Core.cpp, DataDigest.cpp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]
2020-06-16 API changes and standardization
    - Renamed getGuiData to handleApiRequest
    - Moved set_rtc_clock, reset_fep, reset_led and reset_screen into
    handleApiRequest
    - Renamed URL /guiFeed to /api
    [ESParaSite.cpp, HttpCore.cpp]
2020-07-18 Revert "Code cleaning"
    This reverts commit 6e1036224aca7c2c5efc5b46c8c3f67e509f5929.
    [ConfigPortal.cpp, Core.cpp, DataDigest.cpp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]
2020-07-19 Revert "Revert "Code cleaning""
    This reverts commit e6cdfaafacac61651809728367ede181c6b66b5e.
    [ConfigPortal.cpp, Core.cpp, DataDigest.cpp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]
2020-10-22 ESP32 and ESP8266 Compatible
    [partitions_custom.csv]
